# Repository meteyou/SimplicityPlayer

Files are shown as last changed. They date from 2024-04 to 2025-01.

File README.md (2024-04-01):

# Simplicity-Player
This project was born out of a personal motivation: I wanted to bring joy and
comfort to my grandmother, who, due to her visual impairment, can no longer
enjoy reading – one of her lifelong passions. To make her daily life more
enjoyable and to make accessing audiobooks as easy as possible for her, I
developed the SimplicityPlayer.

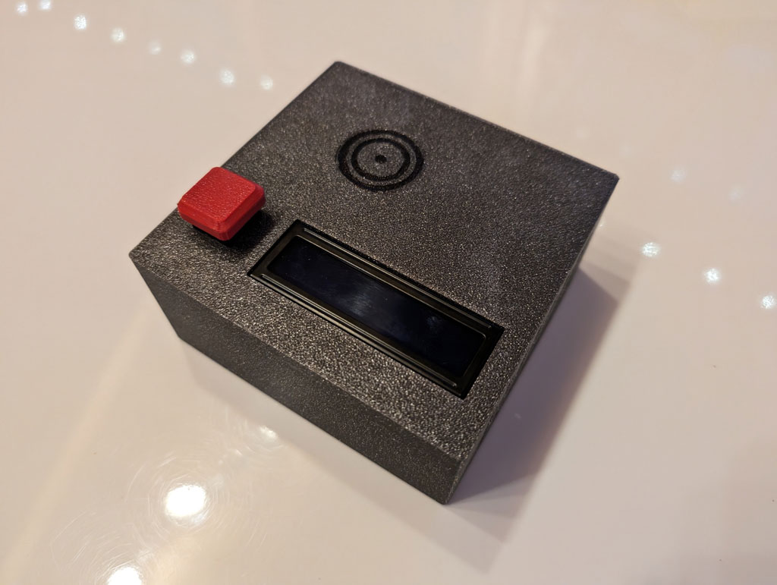
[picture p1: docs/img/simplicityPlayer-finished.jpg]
Simplicity-Player

  
The SimplicityPlayer is a user-friendly audiobook player explicitly designed to
allow people with visual impairments to operate it easily. It utilizes a
physical button for play/pause and provides feedback through a simple LCD, which
is optional for operation. To change the audiobook, it uses RFID cards, which
only need to be placed on the reader.  
  
This project also marks my entry into the world of Python programming. With
little prior experience in Python, it was a challenge, yet it was gratifying
because I had the explicit goal of creating something meaningful for my
grandmother. Throughout the development process, I learned a lot about Python,
hardware interactions on the Raspberry Pi, and managing audio media.  
  
## Features
- **Easy Operation:** The player is controlled using a physical button and RFID
cards, making it easy to use even for individuals with visual impairments.
- **Feedback via LCD:** A simple LCD provides visual feedback designed for high
contrast and easy readability.
- **Customizable and Expandable:** Using a Raspberry Pi as the base, the player
can easily customize and extend with additional features.
- **Web Interface:** A simple web interface allows for remote player control and
audio media management.

## Hardware
- 1x Raspberry Pi 3A+
- 1x InnoMaker HiFi DAC HAT (RPI-HIFI-DAC-PCM5122)
- 1x RFID Reader (RC522)
- 1x LCD1602 + LCD I2C Interface (PCF8574)
- 1x Cherry MX Button
- 1x 4k7 Ohm Resistor
- 4x M2.5x5
- 7x M3x6
- 4x M3 nuts (optional, could be also printed)
- some wires and shrink tubes
- 2x 4-pin female Dupont connectors (optional, could be also soldered)
- 1x 3-pin female Dupont connector (optional, could be also soldered)
- 1x 2-pin female Dupont connector (optional, could be also soldered)
- 1x 2-pin male Dupont connector (optional, could be also soldered)
- 13x female Dupont crimps (optional, could be also soldered)
- 2x male Dupont crimps (optional, could be also soldered)
- Filament for 3D printing (I used ABS, all other filament types should work as
well)

## Wiring
The wiring guide can be found in this repository's
[docs/WIRING.md](docs/WIRING.md) file.

## Installation
The installation guide can be found in this repository's
[docs/INSTALL.md](docs/INSTALL.md) file.

### Contribution
Your contribution to this project is warmly welcomed! Whether you want to
contribute code, report bugs, or suggest improvements, every bit of help is
valuable in making the SimplicityPlayer better and more accessible to everyone.
Please see the [CONTRIBUTING.md](CONTRIBUTING.md) file for more information.  
  
I hope the SimplicityPlayer brings you or your loved ones as joy as it has
brought my grandmother and me.

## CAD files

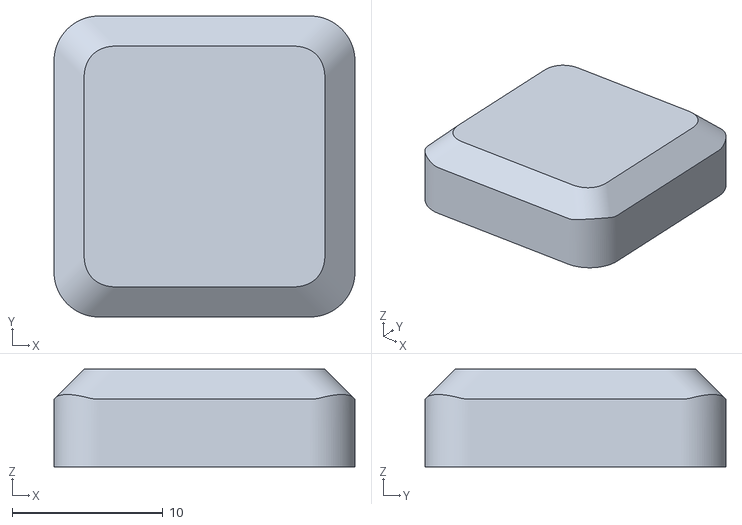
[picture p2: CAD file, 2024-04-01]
STLs/case-button.stl
20.0 x 20.0 x 6.50

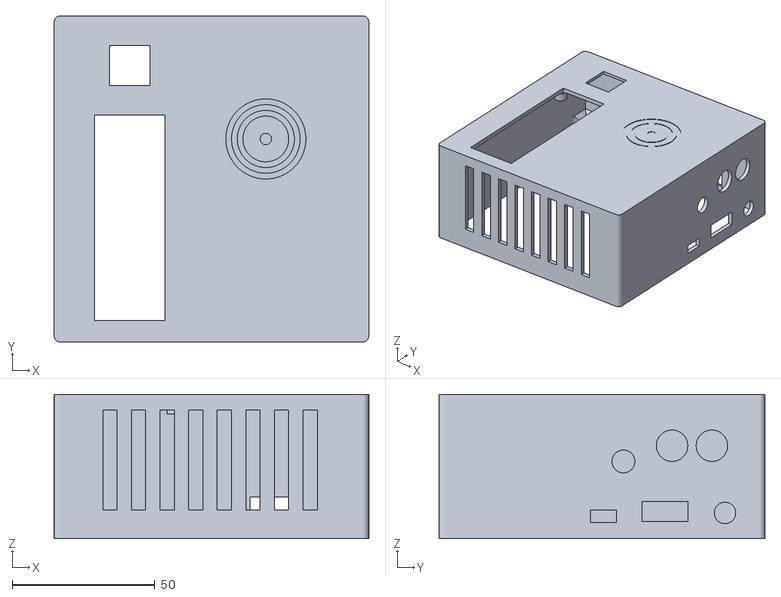
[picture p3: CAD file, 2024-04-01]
STLs/case-upper-part.stl
110.0 x 114.0 x 50.5

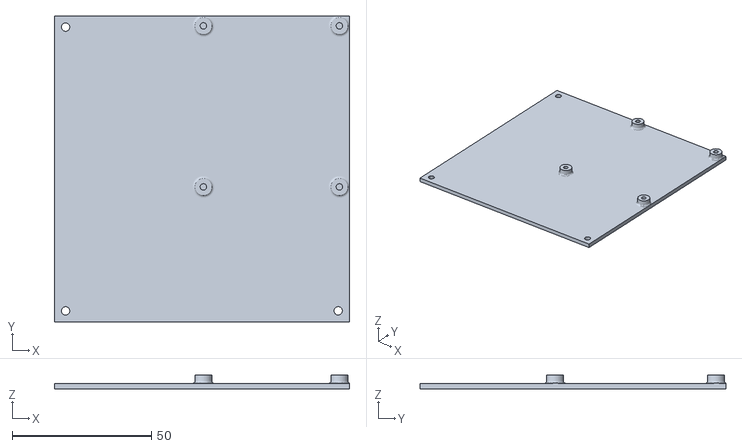
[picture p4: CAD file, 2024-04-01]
STLs/case-base-part.stl
106.1 x 110.0 x 5.00

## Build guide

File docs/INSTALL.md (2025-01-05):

# Installation Guide
This guide will help you set up the SimplicityPlayer on your Raspberry Pi. The
installation process is divided into several steps, each of which is detailed
below.

## Prerequisites
Before you start, make sure you have the following components ready:
- Raspberry Pi 3A+ (other models may work, but the software was tested on this
  model)
- InnoMaker HiFi DAC HAT (RPI-HIFI-DAC-PCM5122)
- RFID Reader (RC522)
- LCD1602 + LCD I2C Interface (PCF8574)
- Cherry MX Button with a 4k7 Ohm Resistor

## Step 1: Prepare the Raspberry Pi
1. Install Raspberry Pi OS Lite on your Raspberry Pi. You can find the official
   installation guide [here](https://www.raspberrypi.org/documentation/installation/installing-images/).
2. Set up your Raspberry Pi, connect it to the network and connect to it via
   SSH.
3. Update the system by running the following commands:
   ```bash
   sudo apt update
   sudo apt upgrade
   ```
4. Enable the I2C & SPI interface by running:
   ```bash
   sudo raspi-config
   ```
   - Select `3 Interfacing Options`.
   - Select `I4 SPI`.
   - `Would you like the SPI interface to be enabled?` -> `Yes`
   - The SPI interface is now enabled.
   - Select `3 Interfacing Options`.
   - Select `I5 I2C`.
   - `Would you like the ARM I2C interface to be enabled?` -> `Yes`
   - The ARM I2C interface is now enabled.
   - Select `Finish`.
   
## Step 2: Set up the Audio Output
1. Connect the InnoMaker HiFi DAC HAT to your Raspberry Pi (only when the
   Raspberry Pi is powered off!)
2. Edit the `/boot/firmware/config.txt` file by running:
   ```bash
   sudo nano /boot/firmware/config.txt
   ```
3. Add the following lines to the end of the file:
   ```
   dtoverlay=allo-boss-dac-pcm512x-audio
   ```
4. Save the file by pressing `Ctrl + X`, then `Y`, and finally `Enter`.
5. Reboot your Raspberry Pi by running:
   ```bash
   sudo reboot
   ```

## Step 3: Set the default audio output
1. Check the audio output devices by running:
   ```bash
   aplay -l
   ```
2. Find the device that corresponds to the InnoMaker HiFi DAC HAT. It should
   look similar to this:
   ```
   card 2: sndrpihifiberry [snd_rpi_hifiberry_dac], device 0: HifiBerry DAC HiFi pcm512x-hifi-0 []
   Subdevices: 1/1
   Subdevice #0: subdevice #0
   ```
3. Edit the `/etc/asound.conf` file by running:
   ```bash
   sudo nano /etc/asound.conf
   ```
4. Insert the following lines to the file:
   ```
   pcm.!default {
       type hw
       card 2
   }
   ctl.!default {
       type hw
       card 2
   }
   ```
   change the `card 2` to the card number you found in step 2.
5. Save the file by pressing `Ctrl + X`, then `Y`, and finally `Enter`.
6. Reboot your Raspberry Pi by running:
   ```bash
   sudo reboot
   ```
7. Test the audio output by running:
   ```bash
   speaker-test -c2 -t wav
   ```
   You should hear a voice saying "Front Left" and "Front Right" from your
   speakers.

## Step 4: Install and configure MPD
1. Install MPD by running:
   ```bash
   sudo apt install alsa-utils mpd
   ```
2. Edit the `/etc/mpd.conf` file by running:
   ```bash
   sudo nano /etc/mpd.conf
   ```
3. Add the following lines to the end of the file:
   ```
   audio_output {
       type "alsa"
       name "RPI-HIFI-DAC-PCM5122"
       device "hw:2,0"
       mixer_control   "Analogue"
   }
   ```
   change the `device "hw:2,0"` to the device number you found in step 2.
4. Save the file by pressing `Ctrl + X`, then `Y`, and finally `Enter`.
5. Enable and restart MPD service by running:
   ```bash
   sudo systemctl enable mpd
   sudo systemctl restart mpd
   ```
## Step 5: Install automount for USB drives
1. Install the required packages by running:
   ```bash
   sudo apt install udevil
   ```
2. Create a new file by running:
   ```bash
   sudo nano /etc/systemd/system/devmon.servic
   ```
3. Insert the following lines to the file:
   ```
   [Unit]
   Description=Automount USB drives
   After=network.target
    
   [Service]
   Type=simple
   User=pi
   Restart=on-abort
   ExecStart=/usr/bin/devmon
    
   [Install]
   WantedBy=multi-user.target
   ```
4. Save the file by pressing `Ctrl + X`, then `Y`, and finally `Enter`.
5. Enable and start the service by running:
   ```bash
   sudo systemctl enable devmon
   sudo systemctl start devmon
   ```

## Step 6: Install the SimplicityPlayer
1. Install the required packages by running:
   ```bash
   sudo apt install python3-virtualenv git
   ```
2. Clone the repository by running:
   ```bash
   cd ~
   git clone https://github.com/meteyou/SimplicityPlayer.git
   ```
3. Create a new virtual environment by running:
   ```bash
   cd ~
   virtualenv -p python3 ./SimplicityPlayer-env
   ./SimplicityPlayer-env/bin/pip install -r ./SimplicityPlayer/requirements.txt
   ```
4. Copy config.ini.example to config.ini by running:
   ```bash
   cp ~/SimplicityPlayer/config.ini.example ~/SimplicityPlayer/config.ini
   ```
5. Copy the systemd service file by running:
   ```bash
   sudo cp ~/SimplicityPlayer/SimplicityPlayer.service /etc/systemd/system/
   ```
6. Enable and start the service by running:
   ```bash
   sudo systemctl enable SimplicityPlayer
   sudo systemctl start SimplicityPlayer
   ```

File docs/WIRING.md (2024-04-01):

# Wiring for the SimplicityPlayer
This guide will help you wire the components of the SimplicityPlayer. The wiring
is relatively simple and requires only a few components. The wiring guide is
split into three parts: the wiring of the Raspberry Pi with the RFID reader, the
wiring of the Raspberry Pi with the LCD, and the wiring of the Raspberry Pi with
the button.  
I soldered the wires directly onto the HiFi DAC HAT, but you can also use Dupont
connectors to connect the components, but in my case the Dupont connectors were
too loose and I had to solder the wires directly onto the HiFi DAC HAT.  
  
Because the HiFi DAC HAT is not a standard component, there is no image for this
component in the Fritzing library. I used the Raspberry Pi 3B as a placeholder.

## Wiring the Raspberry Pi with the RFID Reader
The RFID reader is connected to the Raspberry Pi using the SPI interface. The
wiring is as follows:
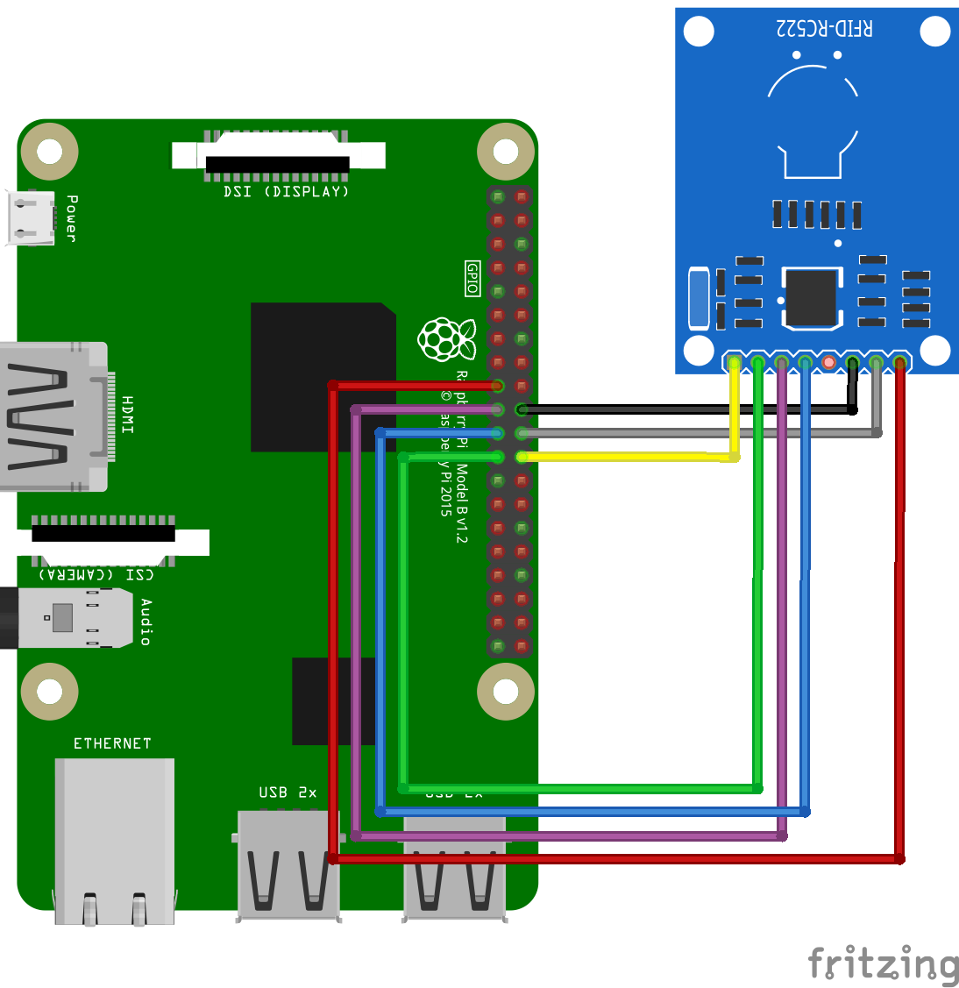
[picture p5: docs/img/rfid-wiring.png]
Wiring the Raspberry Pi with the RFID Reader


## Wiring the Raspberry Pi with the LCD
The LCD is connected to the Raspberry Pi using the I2C interface. The wiring is
as follows:
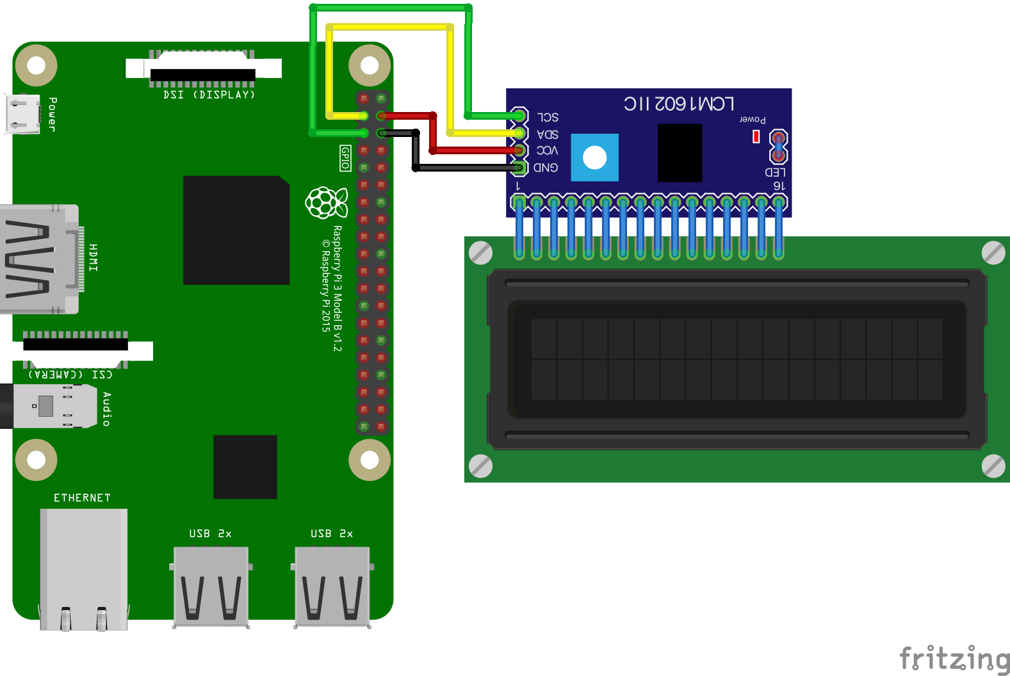
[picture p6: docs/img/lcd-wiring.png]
Wiring the Raspberry Pi with the LCD


## Wiring the Raspberry Pi with the Button
The button is connected to the Raspberry Pi using a GPIO pin and a pull-up
Resistor. The wiring is as follows:
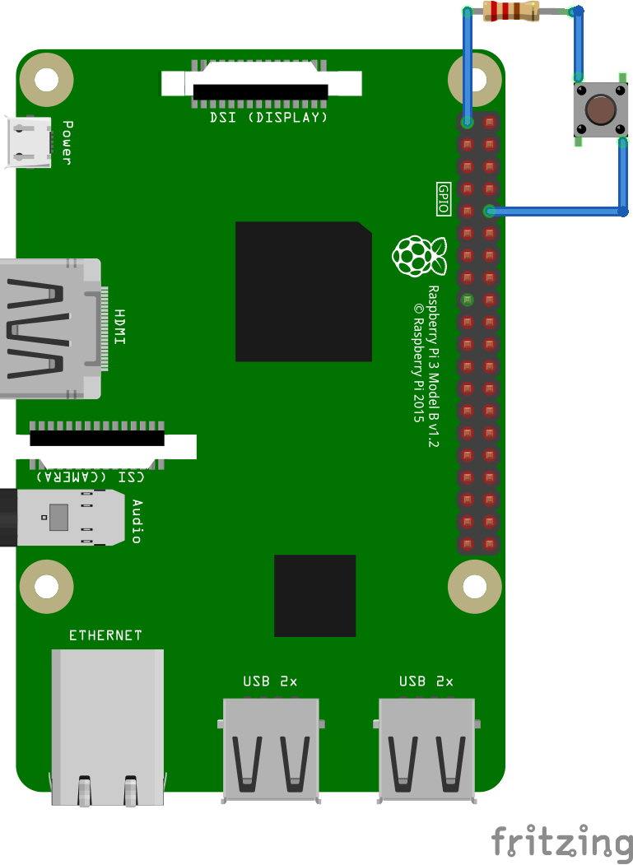
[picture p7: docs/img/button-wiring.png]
Wiring the Raspberry Pi with the Button

(There was no cherry MX button in the Fritzing library, so I used a normal
button and I don't know how to change the resistor value in Fritzing, so I used
a default 220 Ohm resistor instead of the 4k7 Ohm resistor)

## Final Wiring
After wiring all components, the final wiring should look like this:
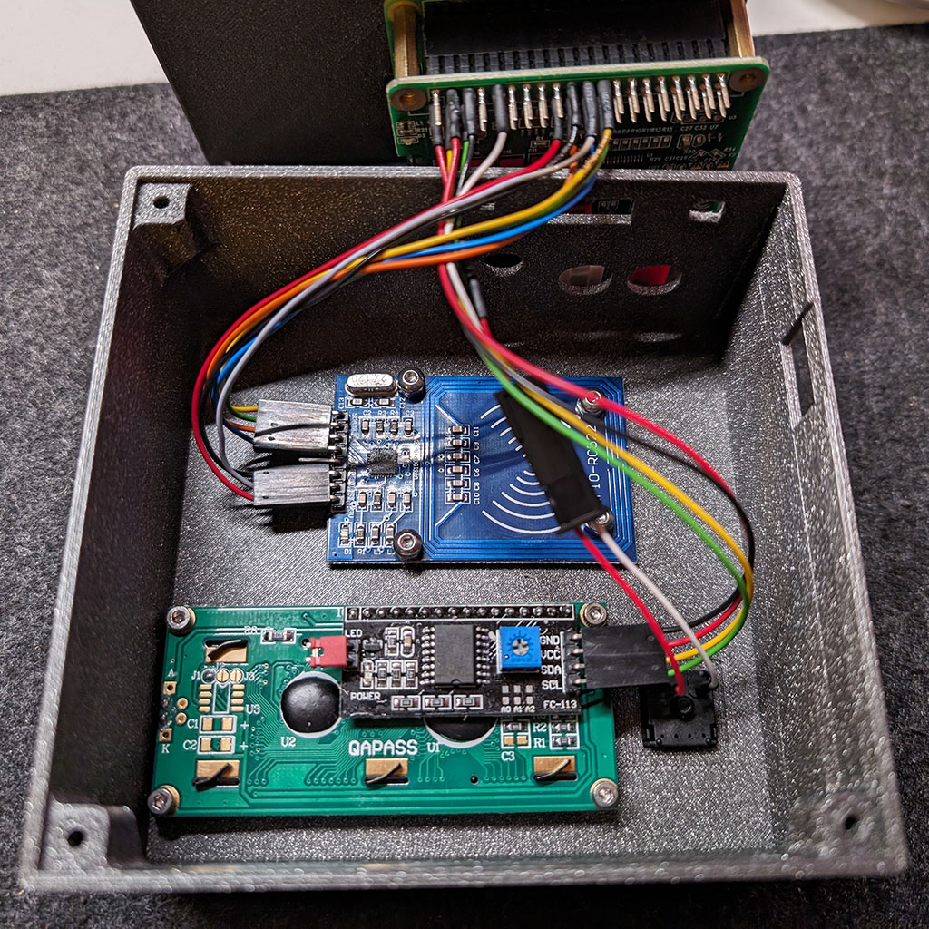
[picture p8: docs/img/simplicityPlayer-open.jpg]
final wiring


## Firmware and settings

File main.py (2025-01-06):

import configparser
import logging
import time

import RPi.GPIO as GPIO
from modules.RFIDModule import RFIDModule
from modules.LCDModule import LCDModule
from modules.MPDModule import MPDModule
from modules.StateManagerModule import StateManagerModule
from modules.TagManagerModule import TagManagerModule
from modules.USBModule import USBModule
from modules.WebServerModule import WebServerModule
from threading import Thread


def main():
    config = configparser.ConfigParser()
    config.read('config.ini')

    logfile = config.get('DEFAULT', 'logfile', fallback='SimplicityPlayer.log')

    logging.basicConfig(filename=logfile,
                        format="%(asctime)s [%(module)s.%(funcName)s] %("
                               "levelname)s: %(message)s")
    logging.getLogger('sp').setLevel(logging.DEBUG)
    logging.getLogger('sp').info('Starting...')

    rfid_read_delay = config.getint('DEFAULT', 'rfid_read_delay', fallback=2)
    toggle_button_pin = config.getint('DEFAULT', 'toggle_button_pin',
                                      fallback=None)

    mpd = MPDModule(config)
    rfid = RFIDModule(config)
    lcd = LCDModule(config, mpd)
    usb = USBModule(config, lcd, mpd)
    tag_manager = TagManagerModule(config)
    state_manager = StateManagerModule(config)

    def button_callback(_):
        mpd.toggle_playback()

    if toggle_button_pin is not None:
        GPIO.setwarnings(False)
        GPIO.setmode(GPIO.BOARD)
        GPIO.setup(toggle_button_pin, GPIO.IN, pull_up_down=GPIO.PUD_DOWN)

        try:
            GPIO.add_event_detect(toggle_button_pin, GPIO.FALLING,
                                  callback=button_callback, bouncetime=800)
        except RuntimeError as e:
            GPIO.cleanup()
            logging.getLogger('sp').error('Failed to add edge detection')
            logging.getLogger('sp').error(e)
            return

    # start the web server in a separate thread
    web_server = WebServerModule(config, lcd, rfid, tag_manager, state_manager)
    web_server_thread = Thread(target=web_server.run)
    web_server_thread.start()

    last_state_store = time.time()
    last_read_tag = None

    try:
        while True:
            if not rfid.is_locked() and not usb.is_working():
                lcd.clear_message()

                # read tag from RFID reader
                tag = rfid.wait_for_tag(rfid_read_delay)

                # if tag is not None and not the same as the last tag read
                if tag and tag != last_read_tag:
                    last_read_tag = tag

                    # get the file name from the tag
                    file_name = tag_manager.get_tag(tag)
                    if file_name is not None:
                        # get the elapsed time from the state manager
                        elapsed = state_manager.get_elapsed(file_name)
                        mpd.play(file_name, elapsed)
                    else:
                        lcd.set_message('Unbekannter Tag')

                # if tag is the same as the last tag read
                elif tag and tag == last_read_tag:
                    time.sleep(rfid_read_delay)

                # if tag is None, reset the last read tag
                elif tag is None and last_read_tag is not None:
                    last_read_tag = None

            # if the RFID reader is locked
            else:
                time.sleep(rfid_read_delay)

            # store the current state every 60 seconds
            state_time_diff = time.time() - last_state_store
            if state_time_diff > 60:
                state_manager.set_current(mpd.get_song())
                last_state_store = time.time()

            # check if a USB stick is inserted
            if not usb.is_working() and usb.exists():
                usb.copy_files()

            # do normal stuff here per tick
            lcd.do_tick()
    except KeyboardInterrupt:
        logging.getLogger('sp').info('Received KeyboardInterrupt.')

    logging.getLogger('sp').info('Stopping...')
    GPIO.cleanup()


if __name__ == "__main__":
    main()

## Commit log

2024-02-21 feat: add play functions and rework WebServerModule
    [main.py]
2024-02-23 refactor: fix some syntax issues in main.py
    [main.py]
2024-02-24 fix: reset last_read_tag when None is read
    This allows, that you can use the same RFID card multiple times without have to use another one between.
    [main.py]
2024-02-25 fix: fix tailwind settings
    [main.py]
2024-02-25 feat: add pause/resume button support
2024-04-01 chore: upload case STLs
    [case-base-part.stl, case-upper-part.stl]
2024-04-01 chore: upload button STL
    [case-button.stl]
2024-04-01 chore: upload CAD
2024-04-01 docs: add the wiring plan
2024-04-01 docs: add the open image to the WIRING.md
2024-04-01 docs: fix the link to the WIRING.md in the README.md
2025-01-05 feat: logging error to init gpio pins
    [main.py]
2025-01-05 feat: add GPIO.cleanup when startup failed
    [main.py]
2025-01-05 feat: add option to set the toggle button pin
2025-01-06 fix: fix toggle_button_pin read from config in main.py
    [main.py]
